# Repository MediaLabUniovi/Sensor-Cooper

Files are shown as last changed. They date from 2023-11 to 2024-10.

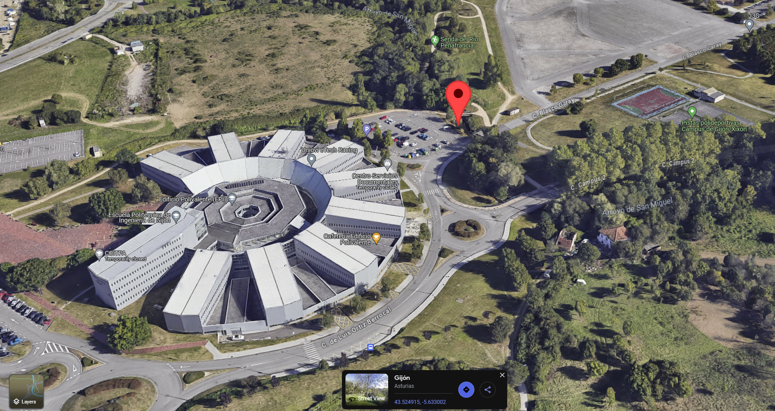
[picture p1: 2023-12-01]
pics/map.png

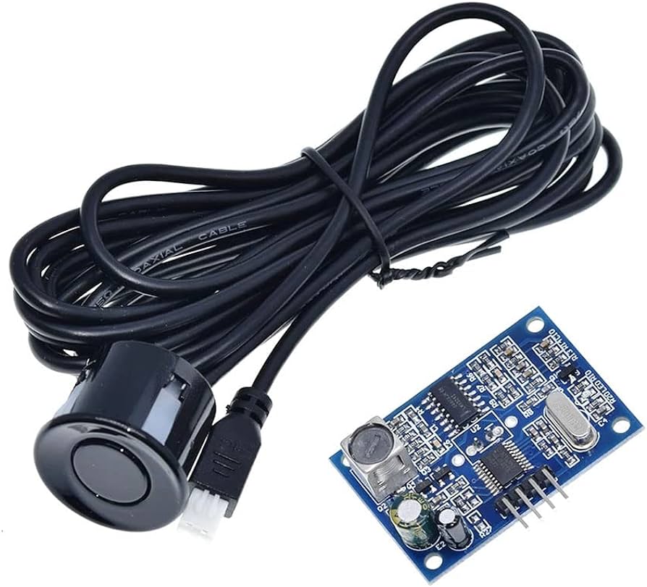
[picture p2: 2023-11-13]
pics/61rPJNXbuNL._AC_UF894,1000_QL80_.jpg

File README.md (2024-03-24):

<div align="right">

english | spanish

</div>



# <p align="justify"> SENSOR COOPER V3.2 - MEDIALAB_ LPWAN: LORA ULTRASONIC SENSOR TO MEASURE SAN MIGUEL'S CREEK WATER LEVEL </p>

<div align="center">

_Powered by_

 

## Project based on: [rwanrooy/TTGO-PAXCOUNTER-LoRa32-V2.1-TTN](https://github.com/rwanrooy/TTGO-PAXCOUNTER-LoRa32-V2.1-TTN)

</div>

___

<div align="justify">

## Table of contents
- [Introduction](https://github.com/medialablpwan/lorawaterlevelmonitoring/tree/main#introduction-leftwards_arrow_with_hook)
- [Main features](https://github.com/medialablpwan/lorawaterlevelmonitoring/tree/main#-main-features-leftwards_arrow_with_hook-)
- [To-Do list](https://github.com/medialablpwan/lorawaterlevelmonitoring/tree/main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)
- [Component list](https://github.com/medialablpwan/lorawaterlevelmonitoring/tree/main#-component-list-leftwards_arrow_with_hook-)
- [Connection list](https://github.com/medialablpwan/lorawaterlevelmonitoring/tree/main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)
- [Flowchart (Simplified!)](https://github.com/medialablpwan/lorawaterlevelmonitoring/tree/main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)
- [Code files](https://github.com/medialablpwan/lorawaterlevelmonitoring/tree/main#code-files-leftwards_arrow_with_hook)
- [Libraries](https://github.com/medialablpwan/lorawaterlevelmonitoring/tree/main#libraries-leftwards_arrow_with_hook)
- [Deployment experiment](https://github.com/medialablpwan/lorawaterlevelmonitoring/tree/main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)
- [License](https://github.com/medialablpwan/lorawaterlevelmonitoring/tree/main#-license-leftwards_arrow_with_hook-)
- [Contact](https://github.com/medialablpwan/lorawaterlevelmonitoring/tree/main#-contact-leftwards_arrow_with_hook-)

</div>

___

<div align="justify">

## Introduction [:leftwards_arrow_with_hook:](https://github.com/medialablpwan/lorawaterlevelmonitoring/tree/main#table-of-contents)

In honour of Martin Cooper, Princesa de Asturias Award 2009, and Arlene Harris and their vision of IoP, The Internet of People, in MediaLab_ LPWAN we wanted to develop an IoT device that could improve the quality of the Polytechnic School of Engineering of Gijón. As a result, the idea of the Cooper Sensor came in as a LoRa device, synchronizable with [The Things Network](https://www.thethingsnetwork.org/), that could be left measuring the water level of San Miguel's creek without any need of mantainance.

</div>

<div align="center">
  
</div>
<br/>

<p align="justify"> With these sensors, the aim is to monitor the possibility of a flood in the main building during the heavy rains season. Specifically, in 2018, a major flood took place turning useless many expensive equipment from the lower floors that were used by the students during the laboratory practices of many subjetcs: </p>

<div align="center">
  
</div>
<br/>
<div align="center">
  
</div>
<br/>
<div align="center">
  
</div>
<br/>

<p align="justify"> In this repo, you will find all the files and teaching guides required to fully understand and even take the creative freedom to improve this project. Folders and files have been given a self-explanatory name to make navigation more intuituve. </p>

___

### <p align="justify"> Main features [:leftwards_arrow_with_hook:](https://github.com/medialablpwan/lorawaterlevelmonitoring/tree/main#table-of-contents) </p>

- <p align="justify"> Developed using LilyGO LoRa32 OLED v2.1_1.6 (ESP32 based board with built-in LoRa capabilities that supports solar recharging and battery management) </p>

  <div align="center">
    
  </div>
  <br/>

- <p align="justify"> Changes made for JSN-SR04T (Ultrasonic distance sensor) </p>

  <div align="center">
    
  </div>
  <br/>

> [!WARNING]
> This sensor is extremely sensitive to physical disturbances. Be sure to perfectly align it perpendicularly to the surface where the ultrasonic beam bounces and also mind having direct vision to it

<div align="justify">

- Dynamic Data Transmission Rate implementation: send interval dynamically changes its value between 20 and 40 minutes depending on the typical deviation from the latest 5 distances sent to The Things Network (By OTAA; file [`payload_formatter.json`](https://github.com/medialablpwan/lorawaterlevelmonitoring/blob/main/payload_formatter.json) is a suggestion on how to decode the sent bytes)

  <div align="center">
    
  </div>
  <br/>

</div>

- <p align="justify"> Custom PCB </p>

  <div align="center">
    
  </div>
  <br/>

> [!TIP]
> Consider soldering female pin connectors so the electronic components can simply be plugged in and unplugged if a repair has to be done

- <p align="justify"> Custom housing to fit all the elements in the most efficient way (Container + Solar panel holder + USB protector) </p>

  <div align="center">
    
  </div>
  <br/>
  <div align="center">
    
  </div>
  <br/>
  <div align="center">
    
  </div>
  <br/>

  > Assembly example:
  <div align="center">
    
  </div>
  <br/>

> [!WARNING]
> Clear colour PETG 3D printing filament is recommended to survive sun radiation and plastic deformations. An O-ring is also a good choice to fix and stabilize the sensor inside of the bell. Four M3 screws are needed to fix the assembly

___

<div align="justify">

### To-do list [:leftwards_arrow_with_hook:](https://github.com/medialablpwan/lorawaterlevelmonitoring/tree/main#table-of-contents)

The following list enumarates all the tasks involved in the researching process of this project and if they have been strictly completed:

- [ ] Full understanding of the development board and its pinout
```diff
- Some pins are conflictive due to poor manufacturer documentation, so testing is still being
- carried out
```

- [x] Full understanding of the sensor working mode and alternative modes

- [x] Sensor code implementation

- [x] LoRa code implementation

- [x] Low power code implementation

- [ ] Low power hardware components
```diff
- A transistor is being tried to be implemented so the sensor can be powered-on from the
- board's 5V pin and powered-off when going to deep slee, but it is getting tricky
```

</div>

<div align="center">
  

  <em>Electric schematic with the transistor</em>
</div>
<br/>

<div align="justify">

- [ ] PCB design
```diff
- As low power hardware has not been fully implemented, PCB has to wait
```

- [x] Casing 3D modeling
      
- [x] Data visualization app

</div>

___

### <p align="justify"> Component list [:leftwards_arrow_with_hook:](https://github.com/medialablpwan/lorawaterlevelmonitoring/tree/main#table-of-contents) </p>

<div align="center">

| Component | Model |
| --- | --- |
| Dev Module  | [LilyGO LoRa32 OLED v2.1_1.6](https://www.tinytronics.nl/shop/en/development-boards/microcontroller-boards/with-lora/lilygo-ttgo-t3-lora32-868mhz-v1.6.1-esp32) |
| Distance sensor  | [JSN-SR04T](https://www.tinytronics.nl/shop/en/sensors/distance/waterproof-ultrasonic-sensor-jsn-sr04t) |
| N-Channel MOSFET  | [IRF540N](https://www.amazon.es/AUKENIEN-Transistor-IRF9540N-Transistores-potencia/dp/B09TJJJXFY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) |
| Resistor  | [2k2](https://www.amazon.es/BOJACK-valores-resistencias-pel%C3%ADcula-carbono/dp/B08FD1XVL6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) |
| Battery  | [18650](https://www.tinytronics.nl/shop/en/power/batteries/18650/eve-18650-li-ion-battery-3100mah-10a-inr18650-33v) |
| Solar panel  | [SYP-S0606](https://www.tinytronics.nl/shop/en/power/solar-energy/solar-panels/solar-panel-with-dc-dc-converter-and-usb-5v-1a) |
| PCB  | [Custom (file included)](https://github.com/medialablpwan/lorawaterlevelmonitoring/tree/main/pcb) |
| Housing  | [Custom (file included)](https://github.com/medialablpwan/lorawaterlevelmonitoring/tree/main/carc) |

</div>

___

### <p align="justify"> Connection list [:leftwards_arrow_with_hook:](https://github.com/medialablpwan/lorawaterlevelmonitoring/tree/main#table-of-contents) </p>

<div align="center">

| JSN-SR04T | Transistor | Resistor | 18650 Shield | SYP-S0606 | LilyGO |
| --- | --- | --- | --- | --- | --- |
| `trigger` | - | - | - | - | `13` |
| `echo` | - | - | - | - | `12` |
| `5v` | `S` | - | - | - | - |
| `GND` | - | `indifferent` | - | - | `GND` |
| - | `G` | `indifferent` | - | - | `15` |
| - | `D` | - | - | - | `5V` |
| - | - | - | `USB-In` | `USB-Out` | - |
| - | - | - | `USB-Out` | - | `USB-In` |

</div>

> Sketched it looks the following way:

<div align="center">
  
</div>
<br/>

> [!CAUTION]
> Board model used in the sketch above is a TTGO T3 v1.3, but pin numbers correspond to those on the v2.1_1.6

___

### <p align="justify"> Flowchart (Simplified!) [:leftwards_arrow_with_hook:](https://github.com/medialablpwan/lorawaterlevelmonitoring/tree/main#table-of-contents) </p>

```mermaid
graph TD;
  A[Turn on] -->|1| B(Wake up if in deep sleep)
  B -->|2| C(Get distance and battery measurement)
  C -->|3| D(Send bytes to TTN)
  D -->|4| E(Time data transmission rate)
  E -->|5| F(Go to deep sleep)
  F -->|6| B
```

___

<div align="justify">

### Code files [:leftwards_arrow_with_hook:](https://github.com/medialablpwan/lorawaterlevelmonitoring/tree/main#table-of-contents)

In this section, a brief description on how the code is distributed among files in [`medialablpwan/lorawaterlevelmonitoring/main/`](https://github.com/medialablpwan/lorawaterlevelmonitoring/tree/main/main), where the code is available and ready to flash or edit, is given:

- [`main.ino`](https://github.com/medialablpwan/lorawaterlevelmonitoring/blob/main/main/main.ino)
  ```C
  /*
  Definition of global functions
  Variables to be stored in the RTC memory
  'setup()' and 'loop()' functions
  */
  ```
- [`sensor.ino`](https://github.com/medialablpwan/lorawaterlevelmonitoring/blob/main/main/sensor.ino)
  ```C
  /*
  Functions and variables needed to make a sensor work
  */
  ```
- [`ddc.ino`](https://github.com/medialablpwan/lorawaterlevelmonitoring/blob/main/main/ddc.ino)
  ```C
  /*
  Functions and variables for the implementation of the dynamic data transfer rate
  */
- [`sleep.ino`](https://github.com/medialablpwan/lorawaterlevelmonitoring/blob/main/main/sleep.ino)
  ```C
  /*
  Functions to activate ESP32's deep sleep mode
  */
- [`ttn.ino`](https://github.com/medialablpwan/lorawaterlevelmonitoring/blob/main/main/ttn.ino)
  ```C
  /*
  Functions from LMIC library
  */
- [`configuration.h`](https://github.com/medialablpwan/lorawaterlevelmonitoring/blob/main/main/configuration.h)
  ```C
  /*
  Sensor macros and boolean toggles
  */
- [`credentials.h`](https://github.com/medialablpwan/lorawaterlevelmonitoring/blob/main/main/credentials.h)
  ```C
  /*
  OTAA keys for TTN synchronization
  */
- [`lmic_project_config.h`](https://github.com/medialablpwan/lorawaterlevelmonitoring/blob/main/main/lmic_project_config.h)
  ```C
  /*
  LoRa frequency band and radio chip selector
  */
A more in depth analysis is given in the code itself as comments explain what each function does.

</div>

> [!TIP]
> The most important files to edit are `sensor.ino`, where any sensor can be implemented, and `configuration.h`, where the peripherals' macros are declared

> [!CAUTION]
> Additional code may be needed if implementing I2C I/O. The functions to make them work are in the original project in [`TTGO-PAXCOUNTER-LoRa32-V2.1-TTN/main/main.ino`](https://github.com/rwanrooy/TTGO-PAXCOUNTER-LoRa32-V2.1-TTN/blob/master/main/main.ino)

___

<div align="justify">

### Libraries [:leftwards_arrow_with_hook:](https://github.com/medialablpwan/lorawaterlevelmonitoring/tree/main#table-of-contents)

- LilyGO board library (Paste the link on the `Preferences` tab and choose `TTGO LoRa32 OLED` as `Board` in Arduino IDE): https://github.com/Xinyuan-LilyGO/LilyGo-LoRa-Series/blob/master/boards/t3_s3_v1_x.json

- LMIC (Copy the contents of the project file `main/lmic_project_config.h` to the library file `arduino-lmic/project_config/lmic_project_config.h` and uncomment the proper frequency for your region. The sketch does always look at the library folder for the configured region!): https://github.com/mcci-catena/arduino-lmic

- QuickMedianLib (To obtain more solid distance values): https://github.com/luisllamasbinaburo/Arduino-QuickMedian

- ESP sleep (To reduce battery consumption): https://github.com/pycom/pycom-esp-idf/blob/master/components/esp32/include/esp_sleep.h

</div>

> [!NOTE]
> Other libraries, like SPI library, are easily downloadable from Arduino IDE

___

___

## <p align="justify"> Deployment experiment [:leftwards_arrow_with_hook:](https://github.com/medialablpwan/lorawaterlevelmonitoring/tree/main#table-of-contents) </p>

### <p align="justify"> The first unit has been deployed near the Polytechnic School of Engineering of Gijón: </p>

<div align="center">
  <img src="https://github.com/medialablpwan/waterlevelcontrol/blob/main/pics/9_Sensor%20Cooper%20en%20Arroyo%20de%20San%20Miguel.jpg" width="600"  style="margin: 10px;"/>
</div>
<br/>
<div align="center">
  <img src="https://github.com/medialablpwan/lorawaterlevelmonitoring/blob/main/pics/map.png" width="600"  style="margin: 10px;"/>
</div>
<br/>

___

### Access the Grafana panel[^1] via this QR code or the link below it:

<div align="center">
  <img src="https://github.com/medialablpwan/waterlevelcontrol/blob/main/pics/qrcode_4f566df1fed52c6e7fd5f661f64ae3eb.balena-devices.com.png" width="600"  style="margin: 10px;"/>
</div>
<br/>

<p align="center"> http://4f566df1fed52c6e7fd5f661f64ae3eb.balena-devices.com:8080/d/vJhQNCZgz/sensores-jsn-sr04t-arroyo-de-san-miguel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 </p>

___

___

## <p align="justify"> License [:leftwards_arrow_with_hook:](https://github.com/medialablpwan/lorawaterlevelmonitoring/tree/main#table-of-contents) </p>

This project is licensed under the [GPL-3.0 license](https://github.com/rwanrooy/TTGO-PAXCOUNTER-LoRa32-V2.1-TTN/blob/master/LICENSE). Contains code from [rwanrooy/TTGO-PAXCOUNTER-LoRa32-V2.1-TTN](https://github.com/rwanrooy/TTGO-PAXCOUNTER-LoRa32-V2.1-TTN)

___

### <p align="justify"> Contact [:leftwards_arrow_with_hook:](https://github.com/medialablpwan/lorawaterlevelmonitoring/tree/main#table-of-contents) </p>

> [!IMPORTANT]
> We will kindly answer doubts and read suggestions: [![Gmail Badge](https://img.shields.io/badge/-Gmail-c14438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)](mailto:medialablpwan@gmail.com)
> 
> More info about our activities: [![Linkedin Badge](https://img.shields.io/badge/-LinkedIn-blue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)](https://www.linkedin.com/groups/9298597/)

_<p align="justify"> Authors: Daniel Rodríguez Moya, Óscar Gijón, Ramón Rubio and MediaLab\_ LPWAN Workgroup :shipit: </p>_

[^1]: Instructions on how to deploy Grafana panels are given on the repo [`medialablpwan/documentacion`](https://github.com/medialablpwan/documentacion).

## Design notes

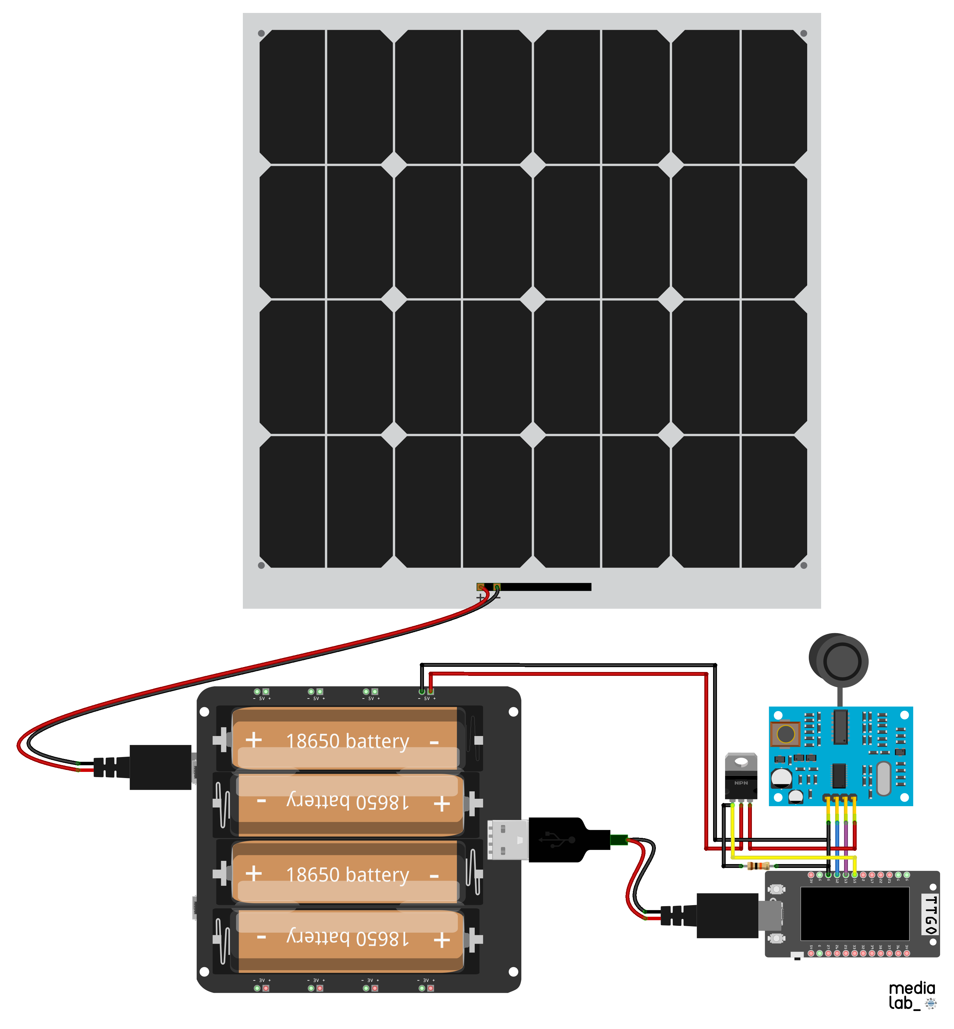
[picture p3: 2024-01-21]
pics/sensor_cooper_v3_3_schematic.png

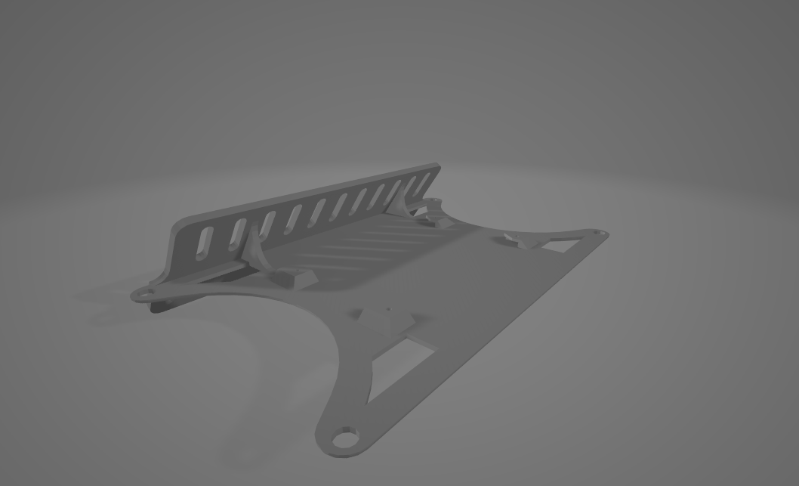
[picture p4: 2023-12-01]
pics/Screenshot 2023-12-01 175633.png

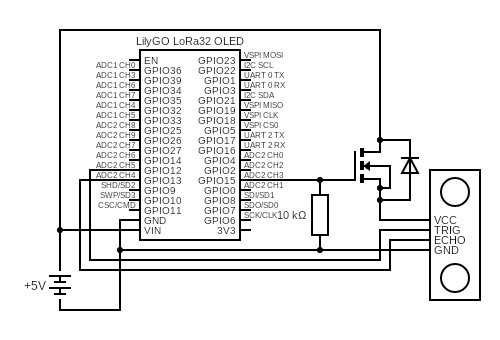
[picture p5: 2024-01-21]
pics/circuit.png

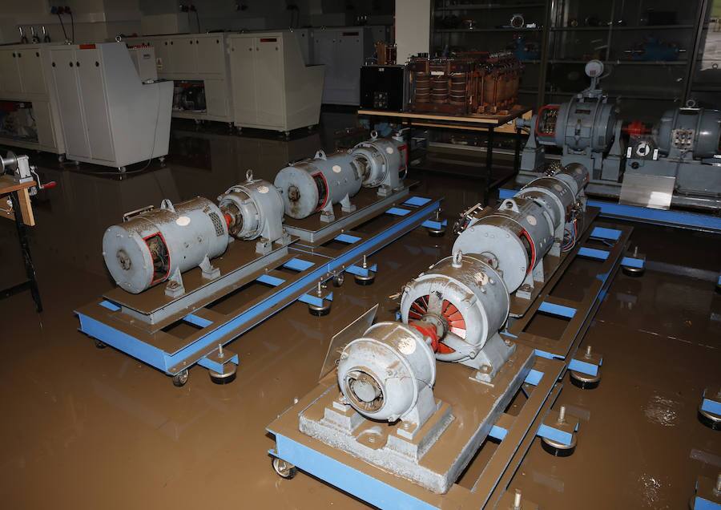
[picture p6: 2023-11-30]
pics/escuela-politecnica-ingenieria (6).jpg

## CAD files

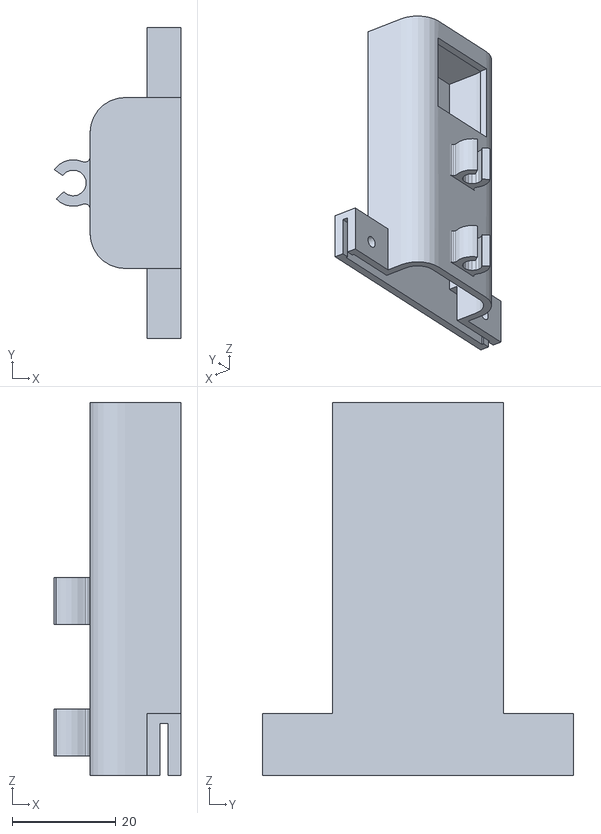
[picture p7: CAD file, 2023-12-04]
3d-printed-parts/conectorUSB_4.stl
24.4 x 60.0 x 72.0

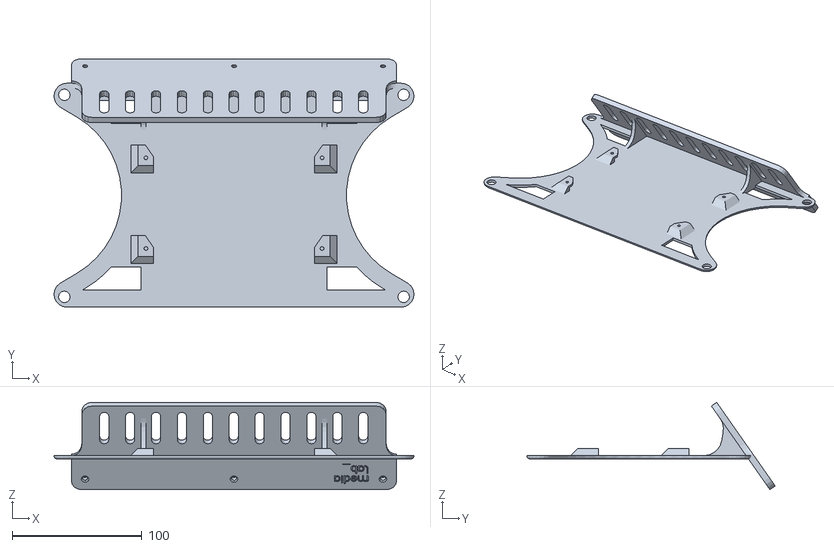
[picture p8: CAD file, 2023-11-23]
3d-printed-parts/soportePlacaSolar_5.stl
278.0 x 191.8 x 67.4

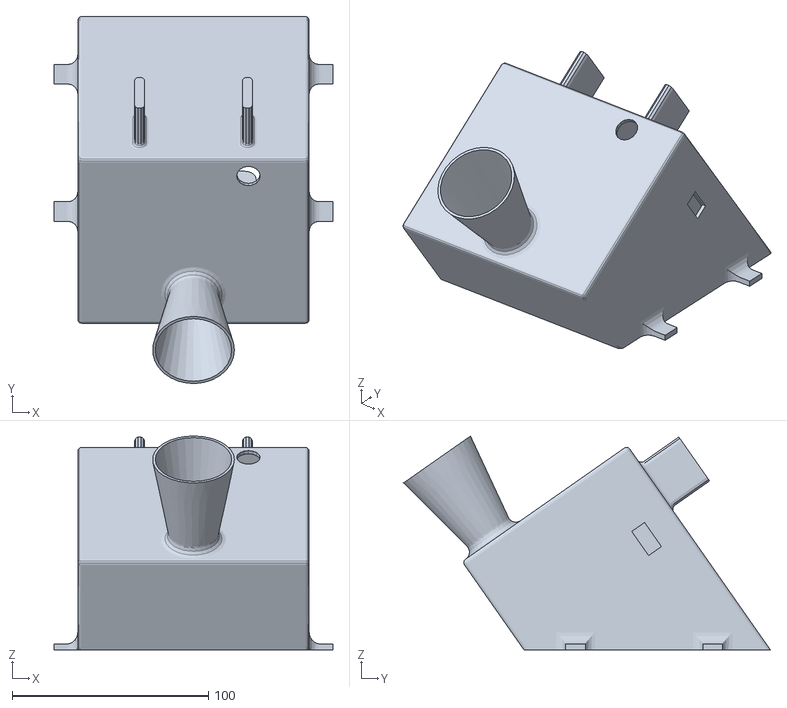
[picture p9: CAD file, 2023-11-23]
3d-printed-parts/tapa_5.stl
142.0 x 187.1 x 109.1

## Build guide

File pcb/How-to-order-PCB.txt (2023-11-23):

How to Order PCB

Please refer to:
https://docs.easyeda.com/en/PCB/Order-PCB

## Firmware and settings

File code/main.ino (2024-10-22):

/* ***********************************************************************************************************************************************************
SENSOR COOPER V3.2 - MEDIALAB LPWAN UNIVERSIDAD DE OVIEDO

Este archivo ha sido modificado de manera considerable para implementar el sensor ultrasónico de distancia JSN-SR04T en vez del original BME280.
El enlace para consultar el proyecto original del usuario de GitHub "rwanrooy" es el siguiente:
https://github.com/rwanrooy/TTGO-PAXCOUNTER-LoRa32-V2.1-TTN.git
*********************************************************************************************************************************************************** */
#include "configuration.h"
#include "rom/rtc.h"

RTC_DATA_ATTR uint32_t count = 0;                           // Message counter, stored in RTC memory, survives deep sleep

RTC_DATA_ATTR uint8_t bufferCircular[TARGET_ARRAY_LENGTH];  // Lista donde guardo los últimos 5 valores enviados a TTN. LA ALOJO EN LA MEMORIA RTC PARA QUE SOBREVIVA AL DEEP SLEEP

static uint8_t txBuffer[3];                                 // Enter the length of the payload in bytes (this has to be more than 3 if you want to receive downlinks)

static uint8_t rxBuffer[1];                                 // Downlink payload

// -----------------------------------------------------------------------------------------------------------------------------------------------------------
// Funcion para enviar el paquete de datos LoRa
// -----------------------------------------------------------------------------------------------------------------------------------------------------------
void send(){
  buildPacket(txBuffer);

  //
  // Gestión del Buffer Circular (AQUÍ PARA EVITAR ENÉSIMAS ITERACIONES) -------------------------------------------------------------------------------------
  //
  carga_valores(txBuffer[0]);
  printArray();
  print_desviacion_estandar();
  print_dynamic_duty_cycle();

#if LORAWAN_CONFIRMED_EVERY > 0
  bool confirmed = (count % LORAWAN_CONFIRMED_EVERY == 0);
#else
  bool confirmed = false;
#endif

  ttn_cnt(count);
  
  ttn_send(txBuffer, sizeof(txBuffer), LORAWAN_PORT, confirmed);
  
  count++;                                                  // send count plus one
}

// -----------------------------------------------------------------------------------------------------------------------------------------------------------
// Funcion para dormir el ESP32 durante el tiempo de duty cycle
// -----------------------------------------------------------------------------------------------------------------------------------------------------------
void sleep(){
#if SLEEP_BETWEEN_MESSAGES == 1
  Serial.println("Iniciando deep sleep...");                // Mostrar mensaje de que se ha iniciado el deep sleep
  Serial.println();

  uint32_t sleep_for = (millis() < dynamic_duty_cycle()) ? dynamic_duty_cycle() - millis() : dynamic_duty_cycle(); // We sleep for the interval between messages minus the current millis, this way we distribute the messages evenly every SEND_INTERVAL millis
  sleep_millis(sleep_for);
#endif
}

// -----------------------------------------------------------------------------------------------------------------------------------------------------------
// Funcion para mostrar mensajes por monitor serial segun se interactue con TTN
// -----------------------------------------------------------------------------------------------------------------------------------------------------------
void callback(uint8_t message){
  if(EV_JOINING == message)Serial.println("Joining TTN...");
  if(EV_JOINED == message)Serial.println("TTN joined!");
  if(EV_JOIN_FAILED == message)Serial.println("TTN join failed");
  if(EV_REJOIN_FAILED == message)Serial.println("TTN rejoin failed");
  if(EV_RESET == message)Serial.println("Reset TTN connection");
  if(EV_LINK_DEAD == message)Serial.println("TTN link dead");
  if(EV_ACK == message)Serial.println("ACK received");
  if(EV_PENDING == message)Serial.println("Message discarded");
  if(EV_QUEUED == message)Serial.println("Message queued");

  if(EV_TXCOMPLETE == message){
    Serial.println(F("EV_TXCOMPLETE (includes waiting for RX windows)"));
    if(LMIC.txrxFlags & TXRX_ACK){
      Serial.println(F("Received ack"));
    }
    if(LMIC.dataLen){
      Serial.print(F("Received "));
      Serial.print(LMIC.dataLen);
      Serial.println(F(" bytes of payload"));
      for (int i = 0; i < LMIC.dataLen; i++){
        if (LMIC.frame[LMIC.dataBeg + i] < 0x10){
          Serial.print(F("0"));
        }
        Serial.print(F("Received payload: "));
        Serial.print(LMIC.frame[LMIC.dataBeg + i], HEX);
      }
      Serial.println();
    }
    sleep();
  }

  if(EV_RESPONSE == message){
    Serial.print(F("[TTN] Response: "));

    size_t len = ttn_response_len();
    uint8_t data[len];
    ttn_response(data, len);

    char buffer[6];
    for(uint8_t i = 0; i < len; i++){
      Serial.print(F(buffer));
    }
    Serial.println();
  }
}

// -----------------------------------------------------------------------------------------------------------------------------------------------------------
// Funcion contador del deep sleep mode para saber que, tras volver de d.s., tiene valores en la memoria RTC
// -----------------------------------------------------------------------------------------------------------------------------------------------------------
uint32_t get_count(){
  return count;
}

// -----------------------------------------------------------------------------------------------------------------------------------------------------------
// Funcion de temporizacion en milisegundos personalizable. Como 'delay()', pero sin detener la ejecución del programa
// -----------------------------------------------------------------------------------------------------------------------------------------------------------
void mi_timer(int intervalo){                                // Supongo un intervalo de 2000
  unsigned long inicioTiempo = millis();                     // Obten el tiempo actual en ms, supongo 14000
  while(millis() - inicioTiempo < intervalo){}               // Mientras 14000... 15000... 16000... - 14000 = 0... 1000... 2000... 3000 (hasta 3000 se cumple) < 2000, me meto en el bucle
}

// -----------------------------------------------------------------------------------------------------------------------------------------------------------
// Funcion para activar o desactivar desde "configuration.h" el monitor serial para debugging
// -----------------------------------------------------------------------------------------------------------------------------------------------------------
void debug_code(){
#if ENABLE_DEBUG == 1
  DEBUG_PORT.begin(SERIAL_BAUD);
#endif
}

// ===========================================================================================================================================================
// Setup main
// ===========================================================================================================================================================
void setup(){
  //
  // Debug ---------------------------------------------------------------------------------------------------------------------------------------------------
  //
  debug_code();

  //
  // Init pines de perifericos que envian por LoRa -----------------------------------------------------------------------------------------------------------
  //
  pinMode(VBATPIN, INPUT);                                  // VBATPIN como input. Es el "sensor" de voltaje de la batería
  pinMode(trigPin, OUTPUT);                                 // trigPin (Rx) como output. Inicia los pulsos ultrasonicos cuando se pone en 'HIGH' 
  pinMode(echoPin, INPUT);                                  // echoPin (Tx) 
  pinMode(VOUT_PIN, OUTPUT);                                // Pin para alimentar al sensor, siempre a 'HIGH' y que se desconecte al entrar el deep sleep

  digitalWrite(VOUT_PIN, HIGH);                             // Poner a 'HIGH' siempre el pin del sensor para que haga de "Vcc"

  //
  // TTN setup -----------------------------------------------------------------------------------------------------------------------------------------------
  //
  if(!ttn_setup()){
    Serial.println("[ERR] Radio module not found!");
    sleep_forever();
  }

  //
  // TTN register --------------------------------------------------------------------------------------------------------------------------------------------
  //
  ttn_register(callback);
  ttn_join();
  ttn_sf(LORAWAN_SF);
  ttn_adr(LORAWAN_ADR);
}

// ===========================================================================================================================================================
// Loop main
// ===========================================================================================================================================================
void loop(){
  ttn_loop();
    
  //
  // Send every SEND_INTERVAL millis -------------------------------------------------------------------------------------------------------------------------
  //
  static uint32_t last = 0;
  static bool first = true;
  if(0 == last || millis() - last > dynamic_duty_cycle()){
    last = millis();
    first = false;
    Serial.println("TRANSMITTING");
    send();
  }
}

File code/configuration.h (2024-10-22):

/* ***********************************************************************************************************************************************************
TTGO LoRa32 V2.1 for The Things Network

Copyright (C) 2019 by Roel van Wanrooy (www.connectix.nl)

This code requires LMIC library by Matthijs Kooijman: https://github.com/matthijskooijman/arduino-lmic

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
You should have received a copy of the GNU General Public License along with this program.  If not, see <http://www.gnu.org/licenses/>.
*********************************************************************************************************************************************************** */
#pragma once

#include <Arduino.h>
#include <lmic.h>
void ttn_register(void (*callback)(uint8_t message));

// -----------------------------------------------------------------------------------------------------------------------------------------------------------
// Configuration
// -----------------------------------------------------------------------------------------------------------------------------------------------------------

// If using a single-channel gateway, uncomment this next option and set to your gateway's channel
//#define SINGLE_CHANNEL_GATEWAY  0

// If you are having difficulty sending messages to TTN after the first successful send, uncomment the next option and experiment with values (~ 1 - 5)
#define CLOCK_ERROR             1

#define DEBUG_PORT              Serial      // Serial debug port
#define SERIAL_BAUD             115200      // Serial debug baud rate
#define ENABLE_DEBUG            0           // Serial debug on/off
#define SLEEP_BETWEEN_MESSAGES  1           // Do sleep between messages
#define SEND_INTERVAL_RELAXED   2400000     // Sleep for these many millis
#define SEND_INTERVAL_INTENSIVE 1200000
#define LORAWAN_PORT            1           // Port the messages will be sent to
#define LORAWAN_CONFIRMED_EVERY 0           // Send confirmed message every these many messages (0 means never)
#define LORAWAN_SF              DR_SF7      // Spreading factor
#define LORAWAN_ADR             1           // Enable ADR
#define TARGET_ARRAY_LENGTH     5           // Tamaño del Buffer Circular

// -----------------------------------------------------------------------------------------------------------------------------------------------------------
// DEBUG
// -----------------------------------------------------------------------------------------------------------------------------------------------------------
#ifdef DEBUG_PORT
#define DEBUG_MSG(...) DEBUG_PORT.printf( __VA_ARGS__ )
#else
#define DEBUG_MSG(...)
#endif

// -----------------------------------------------------------------------------------------------------------------------------------------------------------
// Custom messages
// -----------------------------------------------------------------------------------------------------------------------------------------------------------
#define EV_QUEUED       100
#define EV_PENDING      101
#define EV_ACK          102
#define EV_RESPONSE     103

// -----------------------------------------------------------------------------------------------------------------------------------------------------------
// Sensores
// -----------------------------------------------------------------------------------------------------------------------------------------------------------
#define trigPin         13                  // Defino pin para 'Trig' - JSN-SR04T
#define echoPin         12                  // Defino pin para 'Echo' - JSN-SR04T
#define MAX_DISTANCE    400                 // En 'MAX_DISTANCE' guardaré de forma inmutable la máxima distancia a la que funciona el sensor, unos 400 a 500 cm
#define MIN_DISTANCE    23                  // En 'MIN_DISTANCE' guardaré de forma inmutable la mínima distancia a la que funciona el sensor, por debajo de 24 cm, siempre seran 24 cm
#define VBATPIN         35                  // Defino pin 'vbatPin' - Voltaje
#define VOUT_PIN        0                   // Defino un pin que configuraré a siempre 'HIGH' para alimentar el sensor y que lo desconecte tras el deep sleep

// -----------------------------------------------------------------------------------------------------------------------------------------------------------
// LoRa SPI
// -----------------------------------------------------------------------------------------------------------------------------------------------------------
#define SCK_GPIO        5
#define MISO_GPIO       19
#define MOSI_GPIO       27
#define NSS_GPIO        18
#define RESET_GPIO      23
#define DIO0_GPIO       26
#define DIO1_GPIO       33
#define DIO2_GPIO       32
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

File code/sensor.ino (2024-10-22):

/* ***********************************************************************************************************************************************************
Este archivo ha sido modificado de manera considerable para implementar el sensor ultrasónico de distancia JSN-SR04T en vez del original BME280.
El enlace para consultar el proyecto original del usuario de GitHub "rwanrooy" es el siguiente:
https://github.com/rwanrooy/TTGO-PAXCOUNTER-LoRa32-V2.1-TTN.git
*********************************************************************************************************************************************************** */
#include <QuickMedianLib.h>                                 // Librería para obtener la mediana de un array

// -----------------------------------------------------------------------------------------------------------------------------------------------------------
// JSN-SR04T config
// -----------------------------------------------------------------------------------------------------------------------------------------------------------
int obten_distancia(){
  long duracion;
  int distancia;
  
  digitalWrite(trigPin, LOW);                               // Clear the trigPin by setting it LOW:
  delayMicroseconds(5);

  digitalWrite(trigPin, HIGH);                              // Trigger the sensor by setting the trigPin high for 10 microseconds
  delayMicroseconds(10);
  digitalWrite(trigPin, LOW);
  
  duracion = pulseIn(echoPin, HIGH);                        // Read the echoPin. pulseIn() returns the duration (length of the pulse) in microseconds
  distancia = duracion * 0.034 / 2;                         // Calculate the distance:
  return distancia;
}

// -----------------------------------------------------------------------------------------------------------------------------------------------------------
// Funcion para calcular la mediana de un numero n de muestras de distancia para hacer el dato del nivel del agua más robusto
// -----------------------------------------------------------------------------------------------------------------------------------------------------------
int lista_medidas[5];

uint8_t obten_nivel_mediano(uint8_t muestras){
  int distancia_sonar, distancia_mediana;
  uint8_t nivel_mediana;

  for(uint8_t i = 0; i < muestras; i++){
    distancia_sonar = obten_distancia();

    if(distancia_sonar == 0){                               // Si distancia es 0, implica que superamos el umbral superior. Sin embargo, ésto a veces ocurre sin estar en esta condición, es decir, el sensor tiene fallos físicos
      Serial.print("En el umbral superior: ");
      Serial.println(distancia_sonar);
      uint8_t index = 0;
      while(distancia_sonar == 0 && index < 10){            // "&& i < 'valor'", así puedo evitar pasarme la vida aquí, pero reducir el error
        Serial.print("Umbral superior, corregiendo...       ");
        Serial.println(index);
        distancia_sonar = obten_distancia();
        index++;                                            
        mi_timer(250);                                      // Por ello, en este 'if', itero cada 250ms hasta que de una medida que no sea 0
      }

      if(index == 10){
        Serial.println("UMBRAL SUPERIOR");
        distancia_sonar = MAX_DISTANCE;
      }
      else{
        Serial.print("Umbral superior corregido, ");
      }
    }

    else if(distancia_sonar <= 24 && distancia_sonar >= 1){ // Si estoy entre 1 y 24, el sensor no tiene resolución y siempre da "24"
      Serial.print("En el umbral inferior: ");
      Serial.println(distancia_sonar);
      uint8_t index = 0;
      while((distancia_sonar <= 24 && distancia_sonar >= 1) && index < 10){ // Itero 10 veces, cada intento en franjas de 250ms
        Serial.print("Umbral inferior, corregiendo...       ");
        Serial.println(index);
        distancia_sonar = obten_distancia();
        index++;
        mi_timer(250); 
      }
      
      if(index == 10){                                      // Si 10 veces seguidas da un "24", tendrá razón y lo acepto
        Serial.println("UMBRAL INFERIOR");
        distancia_sonar = MIN_DISTANCE;
      }
      else{
        Serial.print("Umbral inferior corregido, ");        // Si no, es que consiguió una medida "sana" y es con la que me quedo en el array
      }
    }

    else{
      Serial.print("La muestra es: ");
    }

    Serial.println(distancia_sonar);
    lista_medidas[i] = distancia_sonar;
    mi_timer(1000);
  }
  distancia_mediana = QuickMedian<int>::GetMedian(lista_medidas, muestras);
  nivel_mediana = -((100*(distancia_mediana - 24))/376)+100; // Fórmula para calcular de forma lineal el porcentaje de nivel de agua
  return nivel_mediana;
}

// ===========================================================================================================================================================
// FUNCION PRINCIPAL DE "sensor.ino" - Construir el paquete de datos que se enviara por LoRa
// ===========================================================================================================================================================
void buildPacket(uint8_t txBuffer[3]){                      // Uso 'uint8_t' para que todos los datos sean del tamaño de 1byte (8bits)
  //
  // Distancia -----------------------------------------------------------------------------------------------------------------------------------------------
  //
  uint8_t nivel_mediano = obten_nivel_mediano(5);
  Serial.print("Nivel de agua: ");
  Serial.print(nivel_mediano);
  Serial.println("%");

  txBuffer[0] = lowByte(nivel_mediano);                       // Uso únicamente el lowByte ya que estoy hablando de un porcentaje, del 0% al 100%, valores que no superan 255 y caben en un byte

  //
  // Batería -------------------------------------------------------------------------------------------------------------------------------------------------
  //
  float VBAT;
  VBAT = (float)(analogRead(VBATPIN)) / 4095*2*3.3*1.1;     // Conversión del valor analógico del pin a su voltaje correspondiente
  uint8_t nivel_bateria = 50*(VBAT - 2.2);                  // Relacion lineal (muy simplificada) donde asocio el rango 3.1V - 4.2V al 0% - 100%

  Serial.print("Nivel de batería: ");
  Serial.print(nivel_bateria);
  Serial.println("%");

  txBuffer[1] = lowByte(nivel_bateria);
}

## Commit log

2023-12-02 changed PCB to pcb folder name
    [Drill_PTH_Through.DRL, Drill_PTH_Through_Via.DRL, Gerber_BoardOutlineLayer.GKO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]
2023-12-08 corregido fallo de formato README_ES
2024-10-22 update directories
    [conectorUSB_4.stl, configuration.h, soportePlacaSolar_5.stl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]

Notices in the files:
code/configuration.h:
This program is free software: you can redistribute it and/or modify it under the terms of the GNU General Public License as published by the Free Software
